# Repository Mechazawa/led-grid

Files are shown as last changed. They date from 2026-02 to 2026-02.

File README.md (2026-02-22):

# Pixel Panel

A 3D-printable pixel art display powered by WS2812B (NeoPixel) LED strips and [WLED](https://kno.wled.ge/) firmware.

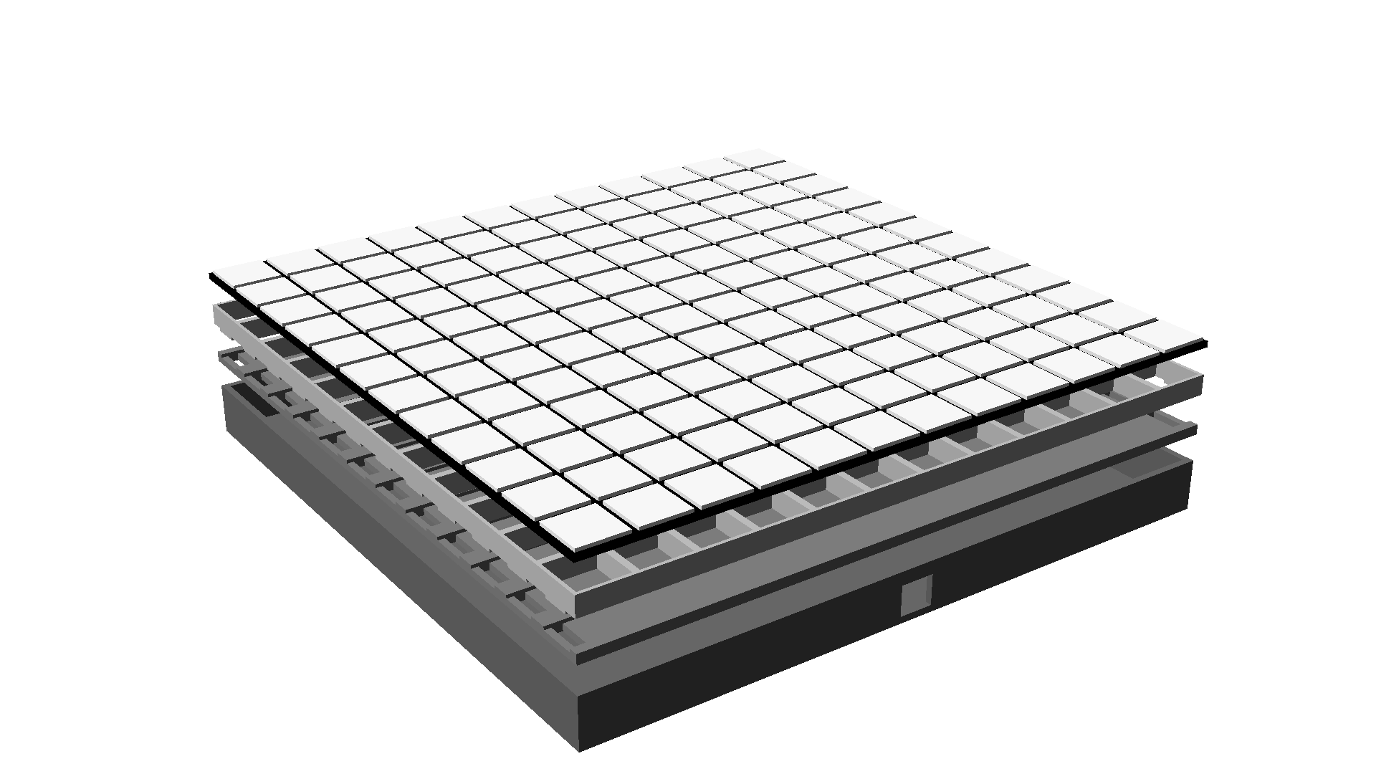
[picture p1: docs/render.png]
Exploded assembly view


demo

## Assembly

The panel is made up of four stacked layers (bottom to top):

| Layer | Description |
| --- | --- |
| **Electronics compartment** | Enclosed box that houses the controller and wiring. Has configurable holes for cable routing. |
| **Back plate** | Holds the LED strips in cutout channels. Wiring holes at each end let strips bend down into the compartment. |
| **Spacer** | Grid of walls that separates each LED into its own cell, preventing light bleed. Alignment keys on the edge walls slot into the back plate cutouts. |
| **Top plate** | The visible face. Black grid padding with raised white pixel diffuser boxes. Printed in two materials. |

<table>
  <tr>
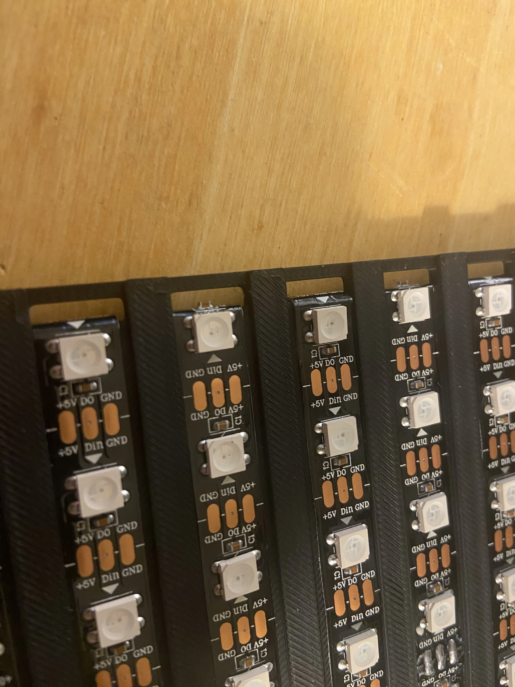
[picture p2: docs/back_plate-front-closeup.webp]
LED strips seated in back plate channels
    <td align="center"></td>
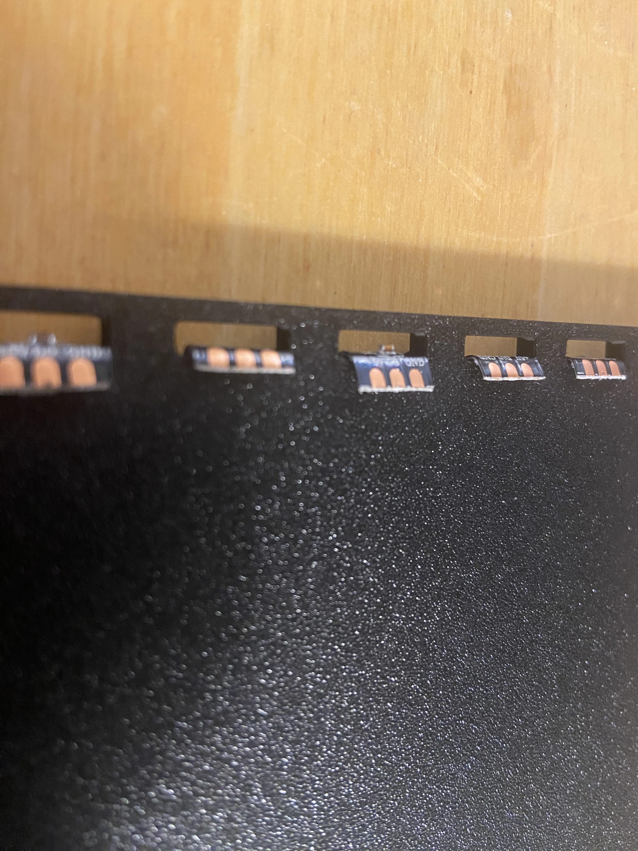
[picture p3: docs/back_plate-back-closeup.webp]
Wiring slots at the edge of the back plate
    <td align="center"></td>
  </tr>
  <tr>
    <td><em>LED strips seated in the back plate channels</em></td>
    <td><em>Wiring slots at the edge route strips into the compartment</em></td>
  </tr>
</table>

## Downloads

> "SO WHY THE FUCK IS THERE CODE? make an ~~EXE~~ STL file and give it to me. STUPID FUCKING SMELLY NERDS"
>
> - [automatic_purpose\_](https://www.reddit.com/r/github/comments/1at9br4/i_am_new_to_github_and_i_have_lots_to_say/) 2024

Grab the latest pre-built STLs from the [releases page](https://github.com/Mechazawa/pixel-panel/releases). Pick the zip that matches your LED strip and grid size:

- **WS2812B / SK6812 — 30 LEDs/m** (~33mm between LEDs, 10mm strip width)
  - `pixel-panel-5050-30leds-8x8.zip`
  - `pixel-panel-5050-30leds-12x12.zip`
- **WS2812B / SK6812 — 60 LEDs/m** (~17mm between LEDs, 10mm strip width)
  - `pixel-panel-5050-60leds-8x8.zip`
  - `pixel-panel-5050-60leds-12x12.zip`

If your strip isn't listed, see the [Building](#building) section to generate STLs for any strip dimensions.

## Hardware

- **LED strips**: Any addressable LED strip (e.g. WS2812B, SK6812). Adjust the LED dimensions in `config.scad` to match your strips.
- **Microcontroller**: Any microcontroller [compatible](https://kno.wled.ge/basics/compatible-controllers/) with [WLED](https://kno.wled.ge/)
- **Firmware**: [WLED](https://kno.wled.ge/)

## Configuration

All dimensions are defined in `config.scad`. Adjust the grid size, LED strip measurements, and part dimensions there. Changing any value automatically propagates to all parts.

## Building

Requires [OpenSCAD](https://openscad.org/) installed (via PATH or macOS app bundle). Currently only Linux and MacOS are supported.

```sh
make          # Build all STL files
make render   # Generate the assembly render
make clean    # Remove build output
```

Output STL files are placed in `build/`:

| File | Material |
| --- | --- |
| `top_plate_padding.stl` | Black filament |
| `top_plate_pixels.stl`  | Transparent filament |
| `spacer.stl` | Black filament |
| `back_plate.stl` | Black filament |
| `compartment.stl` | Black filament |
| `jig.stl` | Any color (reusable) |

## Gluing jig

The jig holds all layers in alignment while gluing.
It's a base plate with L-shaped corner walls that sit slightly above the fully assembled stack.
A large hole in the base lets you push the finished assembly out from below.

## Acknowledgements

Inspired by [Misfitwrx](https://makerworld.com/en/@Misfitwrx)'s [original design on MakerWorld](https://makerworld.com/models/64716), which also has excellent assembly instructions.

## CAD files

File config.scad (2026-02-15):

// General
countX = 12;
countY = 12;

// Based on the LED strips you want to use
ledSize = 4.85; // The size of the LED itself
ledSpacing = 11.7; // The distance edge-to-edge between LEDs on the strip
ledStripWidth = 10.3;
cellSize = ledSize + ledSpacing;

// Top plate
pixelSpacing = 1.90; 
pixelSize = cellSize - pixelSpacing; 
pixelHeight = 1.00; 
plateHeight = 1.80; 

// Back plate
backPlateHeight = 3.0;
backPlateCutoutWidth = 11.0;
backPlateCutoutDepth = 1.0;
backPlateWiringHole = 3.0;

// Spacer
spacerHeight = 6.0;
spacerWall = 2.0;
spacerKeyHeight = backPlateCutoutDepth - 0.1;
spacerKeyWidth = ledStripWidth - 0.2;

// Electronics compartment
compartmentHeight = 15.0;
compartmentWall = spacerWall;
compartmentBaseHeight = 2.0;
compartmentHoles = [
  // width, height
  [10, 9], // Bottom
  [0, 0], // Left
  [0, 0], // Right
  [0, 0], // Top
];

// Gluing jig
jigClearance = 0.3;
jigWall = 3.0;
jigCornerLength = 30.0;
jigBaseHeight = 2.0;
jigHoleMargin = 15.0;

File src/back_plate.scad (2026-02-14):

include <../config.scad>;

module back_plate() {
    totalWidth = countX * cellSize;
    totalDepth = countY * cellSize;

    difference() {
        cube([totalWidth, totalDepth, backPlateHeight]);

        for (y = [0:countY-1]) {
            // Cutout channel for LED strip
            translate([-0.01,
                       y * cellSize + (cellSize - backPlateCutoutWidth) / 2,
                       backPlateHeight - backPlateCutoutDepth])
                cube([totalWidth + 0.02, backPlateCutoutWidth, backPlateCutoutDepth + 0.01]);

            // Left wiring hole
            translate([spacerWall,
                       y * cellSize + (cellSize - backPlateCutoutWidth) / 2,
                       -0.01])
                cube([backPlateWiringHole, backPlateCutoutWidth, backPlateHeight + 0.02]);

            // Right wiring hole
            translate([totalWidth - spacerWall - backPlateWiringHole,
                       y * cellSize + (cellSize - backPlateCutoutWidth) / 2,
                       -0.01])
                cube([backPlateWiringHole, backPlateCutoutWidth, backPlateHeight + 0.02]);
        }
    }
}

back_plate();

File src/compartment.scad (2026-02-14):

include <../config.scad>;

module compartment() {
    totalWidth = countX * cellSize;
    totalDepth = countY * cellSize;

    difference() {
        // Outer shell
        cube([totalWidth, totalDepth, compartmentHeight]);

        // Inner cavity (open top)
        translate([compartmentWall, compartmentWall, compartmentBaseHeight])
            cube([totalWidth - 2 * compartmentWall,
                  totalDepth - 2 * compartmentWall,
                  compartmentHeight - compartmentBaseHeight + 0.01]);

        // Bottom wall hole (Y=0 face)
        if (compartmentHoles[0][0] > 0 && compartmentHoles[0][1] > 0)
            translate([(totalWidth - compartmentHoles[0][0]) / 2,
                       -0.01,
                       compartmentBaseHeight])
                cube([compartmentHoles[0][0], compartmentWall + 0.02, compartmentHoles[0][1]]);

        // Left wall hole (X=0 face)
        if (compartmentHoles[1][0] > 0 && compartmentHoles[1][1] > 0)
            translate([-0.01,
                       (totalDepth - compartmentHoles[1][0]) / 2,
                       compartmentBaseHeight])
                cube([compartmentWall + 0.02, compartmentHoles[1][0], compartmentHoles[1][1]]);

        // Right wall hole (X=max face)
        if (compartmentHoles[2][0] > 0 && compartmentHoles[2][1] > 0)
            translate([totalWidth - compartmentWall - 0.01,
                       (totalDepth - compartmentHoles[2][0]) / 2,
                       compartmentBaseHeight])
                cube([compartmentWall + 0.02, compartmentHoles[2][0], compartmentHoles[2][1]]);

        // Top wall hole (Y=max face)
        if (compartmentHoles[3][0] > 0 && compartmentHoles[3][1] > 0)
            translate([(totalWidth - compartmentHoles[3][0]) / 2,
                       totalDepth - compartmentWall - 0.01,
                       compartmentBaseHeight])
                cube([compartmentHoles[3][0], compartmentWall + 0.02, compartmentHoles[3][1]]);
    }
}

compartment();

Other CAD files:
src/plate.scad
src/render.scad
src/spacer.scad
src/top_plate.scad

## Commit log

2026-02-14 Move config
    [config.scad, plate.scad]
2026-02-14 Back plate
    [config.scad, top_plate.scad]
2026-02-14 Electronics compartment
    [back_plate.scad, compartment.scad]
2026-02-14 Glue jig
    [config.scad]
2026-02-14 Add some docs
    [config.scad]
2026-02-15 Fix spacer key width to fit better
    [config.scad]
